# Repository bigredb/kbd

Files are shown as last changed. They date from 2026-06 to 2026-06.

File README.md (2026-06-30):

# Zigbee Touch Keypad

I wanted a door keypad that actually looked good on the wall — slim, wireless, no visible screws, no cloud dependency. Something I could mount next to the front door, punch in a code, and have Home Assistant react instantly. Off-the-shelf Zigbee keypads exist, but they're usually expensive, mains-powered, or locked to one ecosystem. So I built my own.

The result is a battery-powered touch keypad about the size of a pez dispenser. It runs for roughly **six months** on a single charge, talks **Zigbee** to whatever coordinator you already run, and wakes from deep sleep the moment you touch a key. This repo has everything you need to build one yourself: Gerber files, a 3D-printable case, and working firmware.

The firmware ships as a **Zigbee** end-device example. The same **ESP32-C6** board is equally happy running **Matter** or **Thread** — the touch handling and power logic stay the same; only the radio stack changes.

<p align="center">
  <a href="https://www.youtube.com/watch?v=2Mcdj70jt44">
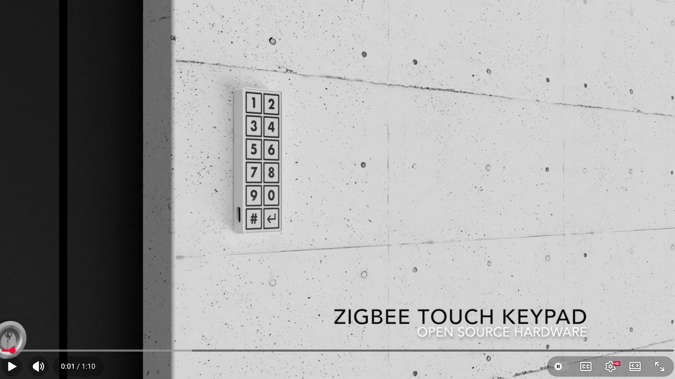
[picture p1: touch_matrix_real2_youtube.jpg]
Watch the keypad demo on YouTube
    
  </a>
</p>

## What it looks like on the wall

The design goal was something that disappears into a modern entryway. A white slab on textured walls, twelve touch buttons, no mechanics to wear out.

<p align="center">
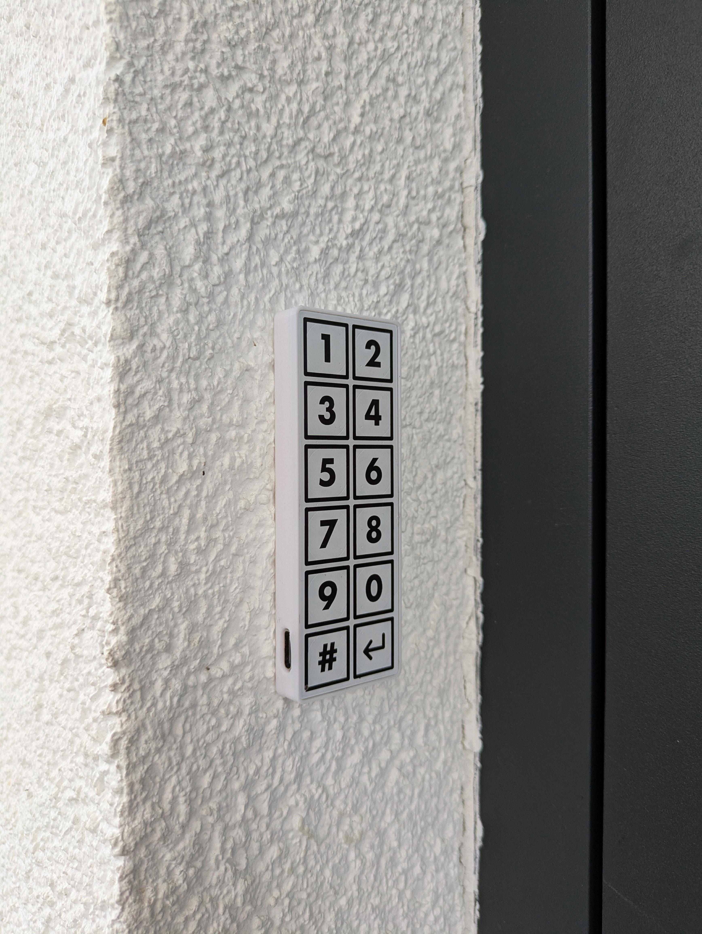
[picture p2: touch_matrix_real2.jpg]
Finished keypad mounted on a wall beside a door
  
</p>

Early renders explored proportions and mounting position before the first PCB arrived. Getting the aspect ratio right mattered — too tall and it looks just weird, too wide and it reads as a light switch.

<p align="center">
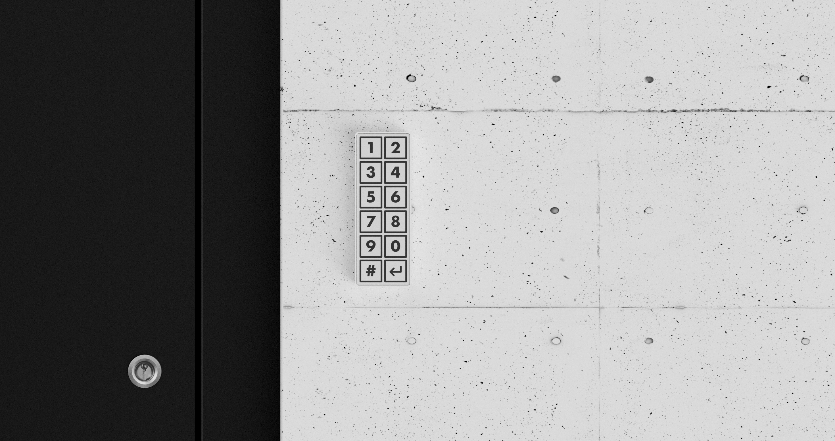
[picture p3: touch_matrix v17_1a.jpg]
Early prototype mounted on a concrete wall
  
 </p>

The front panel is a 2×6 grid: digits **1–9**, **0**, a **clear** key, and **enter**. Labels are printed directly on the PCB solder mask — no separate overlay, no glue, nothing to peel off after two winters.

---

## Tear it down

Pop the case apart and the internals are deliberately simple. A custom backplane PCB, a 1300 mAh LiPo filling most of the volume, and an ESP32-C6 dev board at the bottom with a USB-C port for charging and flashing.

<p align="center">
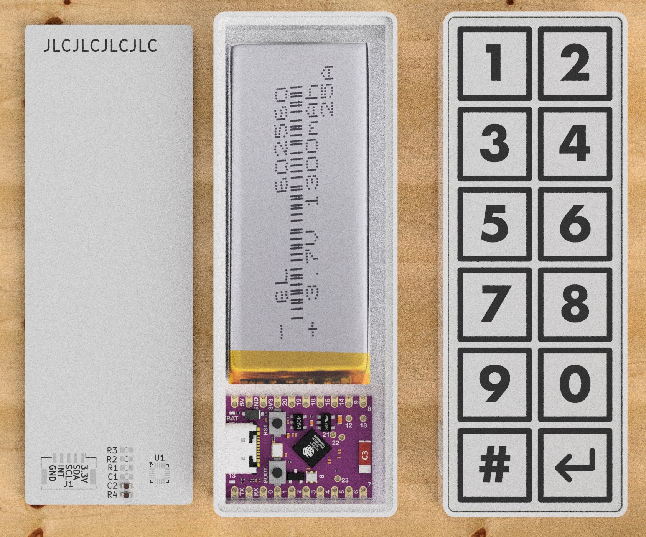
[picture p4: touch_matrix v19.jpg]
Exploded view showing PCB back, battery and ESP32 assembly, and keypad face
  
</p>

The whole assembly is rather light hence can be mounted to the wall with a few bites of white tack. For scale:

<p align="center">
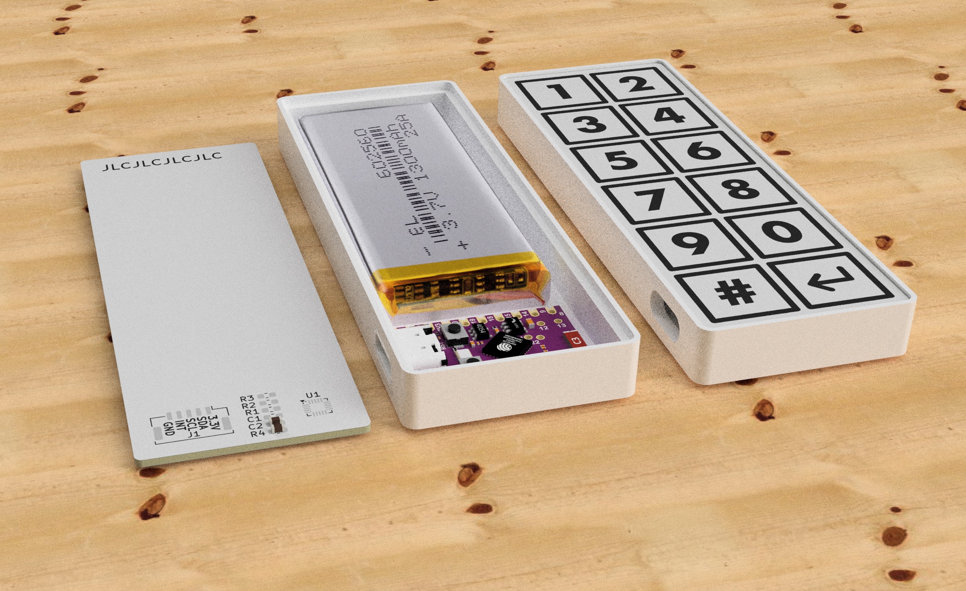
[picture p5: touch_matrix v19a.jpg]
Exploded assembly on a wooden workbench
  
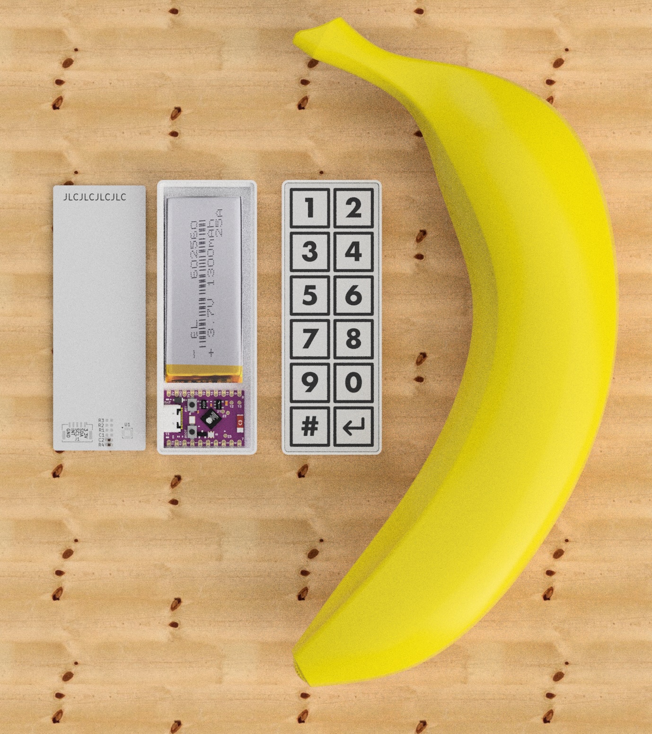
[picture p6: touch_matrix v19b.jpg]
All parts laid out next to a banana for size comparison
  
</p>

Three layers, top to bottom:

1. **Keypad face** — the touch matrix PCB you see and press
2. **Electronics bay** — battery, ESP32-C6, MPR121 touch controller
3. **Back cover** — 3D-printed shell (`case_mid_final.stl`) that clips on without screws

The onboard LED sits inside the white case that is somewhat translucent. When the device wakes from deep sleep it glows briefly; each key press flashes it again so you always know your touch registered.

---

## Order the PCB

You don't need to lay out a board from scratch. The Gerber files are in this repo and ready to upload to any fab. I've been using [JLCPCB](https://jlcpcb.com) — pick a colour scheme, drop in the matching zip, and order. No CAM fixes, no layer renaming, no back-and-forth with support.

| File | Colour scheme |
|---|---|
| `touch_matrix_Y24.zip` | **Black on white** — black key labels on a white PCB (latest revision) |
| `touch_matrix_Y23.zip` | **White on black** — white key labels on a black PCB |

Same layout, same touch pads — only the silkscreen colours differ. Choose whichever fits your wall and enclosure.

The back of the PCB carries the JLC order markings and a five-pin header for the MPR121:

| Pin | Function |
|-----|---|
| GND | Ground |
| INT | Interrupt (wake from sleep) |
| SCL | I²C clock |
| SDA | I²C data |
| 3.3 V | Power |

---

## Wire it up

The firmware expects this pin mapping on the ESP32-C6 DevKitC-1:

| Signal | GPIO | Notes |
|---|---|---|
| I²C SDA | 18 | MPR121 data |
| I²C SCL | 4 | MPR121 clock |
| IRQ | 6 | MPR121 interrupt — also the deep-sleep wake source |
| Battery ADC | 2 | Voltage divider input |
| BOOT button | 9 | Hold 3 s for Zigbee factory reset |

The wiring is very straigtforward - simply connect all the pins as described, connect the battery to ESP32-C6 bat pins, route 3.3V and ground to the PCB and done. If you would like the battery SOC reported, you will need to add an additional voltage device to the battery pins. 

The twelve MPR121 channels map to the front-panel keys like this:

| Channel | Key |
|---|-----|
| 0–8 | 1 – 9 |
| 9 | 0 |
| 10 | Clear |
| 11 | Enter |

For now the software allows coes up to eight digits.

---

## Flash the firmware

The project builds with [PlatformIO](https://platformio.org/). Clone the repo, connect the ESP32-C6 over USB-C, and:

```bash
pio run --target upload
```

To watch the serial log while pairing:

```bash
pio device monitor
```

The build targets **Zigbee end-device mode** (`ZIGBEE_MODE_ED`) with a custom partition table (`partitions_zigbee.csv`) that reserves flash for Zigbee network storage. Dependencies are pulled automatically — the main one is the Adafruit MPR121 library.

---

## Join your Zigbee network

On first boot the keypad scans for a coordinator. Dots print on the serial console at 115200 baud until it joins. In Home Assistant that means adding it through ZHA or Zigbee2MQTT — the device shows up as manufacturer **DrDoms**, model **KeyPad2**.

Two Zigbee endpoints are exposed:

| Endpoint | Cluster | What it reports |
|---|---|---|
| 1 | Analog Input + Battery | Entered passcode, battery voltage |
| 2 | Analog Input | Battery state of charge (%) |

The passcode flow works like this:

1. Touch digits on the pad — the LED confirms each press.
2. Press **Enter**. The code is reported on endpoint 1 as an analog value.
3. Battery level is reported at the same time.
4. Two seconds later the reported value resets to **0**, ready for the next entry.

**Leading 1:** The firmware always prepends a **1** to every code before sending it. The input buffer starts as `"1"` and resets to `"1"` after clear or enter. This is because ensure that leading zeros in your entered code are not stripped as the value is purely numeric, not a string. 

Press **Clear** at any time to wipe the buffer and start over.

### Home Assistant with ZHA

Once the keypad is flashed, getting it into [Home Assistant](https://www.home-assistant.io/) through [ZHA](https://www.home-assistant.io/integrations/zha/) takes about two minutes.

1. In Home Assistant go to **Settings → Devices & Services → Zigbee Home Automation** and open your coordinator.
2. Click **Add device** and confirm — this opens the network for joining.
3. Wake the keypad by touching any key. Within a few seconds it should appear as **DrDoms KeyPad2**.
4. Finish the interview if ZHA asks — no special configuration is needed.

After pairing, open the device page and note the entity names ZHA created. The important one is the **Passcode** analog-input sensor — in my setup it shows up as `sensor.drdoms_keypad2_passcode`. You will also see battery voltage and percentage sensors from the second endpoint. Entity IDs can differ slightly depending on your ZHA version and how many Espressif devices you already have, so always copy the names from your own device page rather than assuming mine.

When you enter a code and press **Enter**, that sensor updates to the numeric value of your input — including the leading **1** described above — holds it for two seconds, then drops back to **0**. That brief window is what your automations listen for.

The file `keypad_automation.yaml` is a worked example that maps passcodes to actions — opening a door, raising a cover, closing a cover. Import it as a starting point and adapt it to your home:

1. Go to **Settings → Automations & Scenes → Create Automation → Edit in YAML** (top-right menu).
2. Paste the contents of `keypad_automation.yaml`, or save the file to your Home Assistant `packages/` folder if you use [packages](https://www.home-assistant.io/docs/configuration/packages/).
3. Replace every `entity_id` with the ones from your installation — the passcode sensor, the door button, the cover, and so on.
4. Change the template values to match the codes you actually want. Each `if` block compares the passcode sensor against a number; when they match, the action runs. Remember to account for the leading **1** — the sample value `12345` means you typed **2-3-4-5** on the pad, not **1-2-3-4-5**. A code you enter as **0-1** will appear as **101** in Home Assistant.

```yaml
# Example: open a cover when passcode 12345 is entered
- if:
    - condition: template
      value_template: "{{ states('sensor.drdoms_keypad2_passcode') | int(0) == 12345 }}"
  then:
    - action: cover.open_cover
      target:
        entity_id: cover.basement_control_cover
```

The sample automation listens on two sensor entities because entity naming changed between ZHA versions — `sensor.espressif_zigbeeanalogdevice_power` is the older name, `sensor.drdoms_keypad2_passcode` is the current one. Keep whichever matches your device and delete the other trigger block.

To find the exact integer your keypad sends for a given code, enter the code, press **Enter**, and watch the sensor in **Developer Tools → States**. Use that number in your template condition.

### Matter and Thread

This repo demonstrates Zigbee because it's the fastest path to a working smart-home integration. But the ESP32-C6 has a native 802.15.4 radio, so porting to **Thread** and **Matter** is straightforward — the touch scanning, debouncing, battery ADC, and deep-sleep wake logic in `main.cpp` don't care which protocol sends the numbers upstream. Espressif's [ESP-Matter](https://github.com/espressif/esp-matter) SDK is the place to start if you want to go that route.

---

## Power: six months on a charge

Battery life was the hardest constraint. A keypad that's dead every two weeks is worse than no keypad at all.

The trick is aggressive deep sleep. After ten seconds without a touch, the firmware shuts everything down and puts the MPR121 into its slowest scan rate. The ESP32-C6 draws almost nothing. The next finger on the pad pulls the MPR121 interrupt line low, the MCU wakes, re-initialises I²C, and is ready to scan within milliseconds.

With a 1300 mAh cell and typical use — a few code entries per day — that works out to roughly **half a year** between USB-C charges. Battery voltage and percentage are reported over Zigbee so you can set a low-battery alert in Home Assistant before it goes flat.

---

## Day-to-day use

1. Walk up and touch a key. The LED glows through the case as the device wakes.
2. Enter your code. Each digit flashes the LED.
3. Press **Enter** to send it to your automation.
4. Walk away. Ten seconds later it sleeps again.

If you need to re-pair — new coordinator, corrupted network, that sort of thing — hold the **BOOT** button for more than three seconds. The device factory-resets its Zigbee stack and reboots.

---

## What's in this repo

```
keypad/
├── main.cpp                  # Touch handling, Zigbee reporting, power management
├── platformio.ini            # Board target, libraries, build flags
├── partitions_zigbee.csv     # Flash layout with Zigbee storage partitions
├── case_mid_final.stl        # 3D-printable enclosure mid-section
├── touch_matrix_Y24.zip      # PCB Gerbers — black on white
├── touch_matrix_Y23.zip      # PCB Gerbers — white on black
├── keypad_automation.yaml    # Home Assistant example — passcode → actions
└── touch_matrix_*.jpg        # Photos from the build
```

---

## License

| Part | License | File |
|---|---|---|
| Firmware (`main.cpp`, build config) | [MIT License](LICENSE) | `LICENSE` |
| Hardware (PCB Gerbers, STL, design files) | [CERN Open Hardware Licence v2 — Strongly Reciprocal](LICENSE.hardware) | `LICENSE.hardware` |

It really works well - has been my method of entry for the past year. If you make a variant — Matter port, different key layout, waterproof enclosure — I'd love to see it.

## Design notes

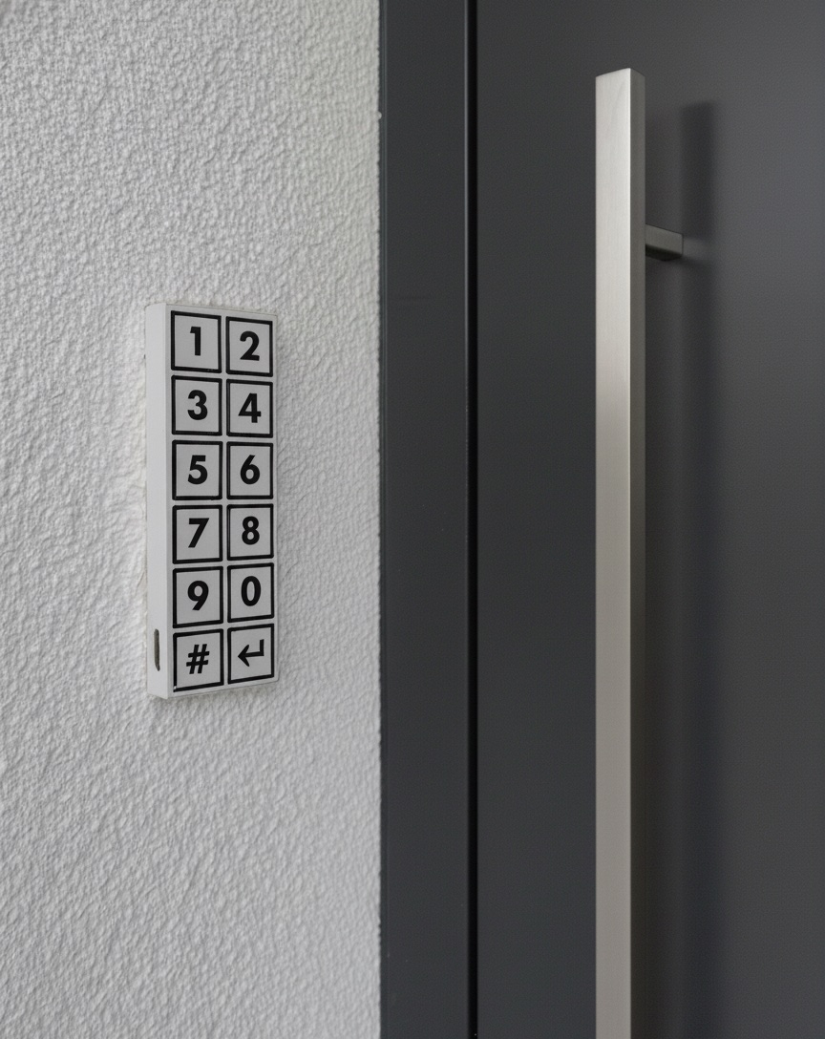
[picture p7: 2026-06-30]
touch_matrix_real.jpg

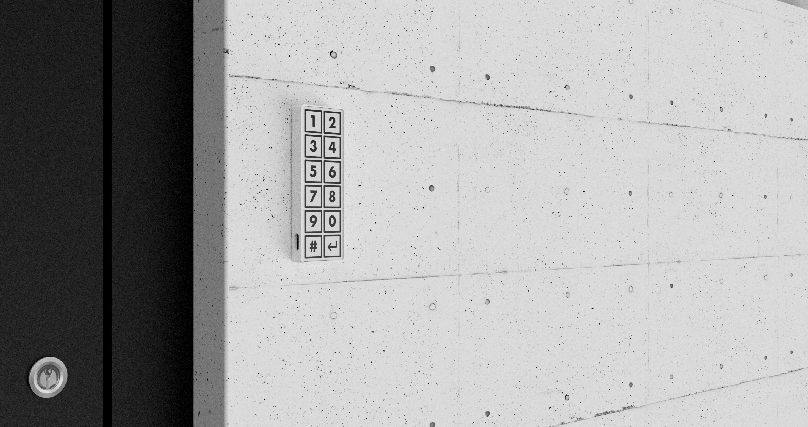
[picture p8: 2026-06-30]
touch_matrix v17_1b.jpg

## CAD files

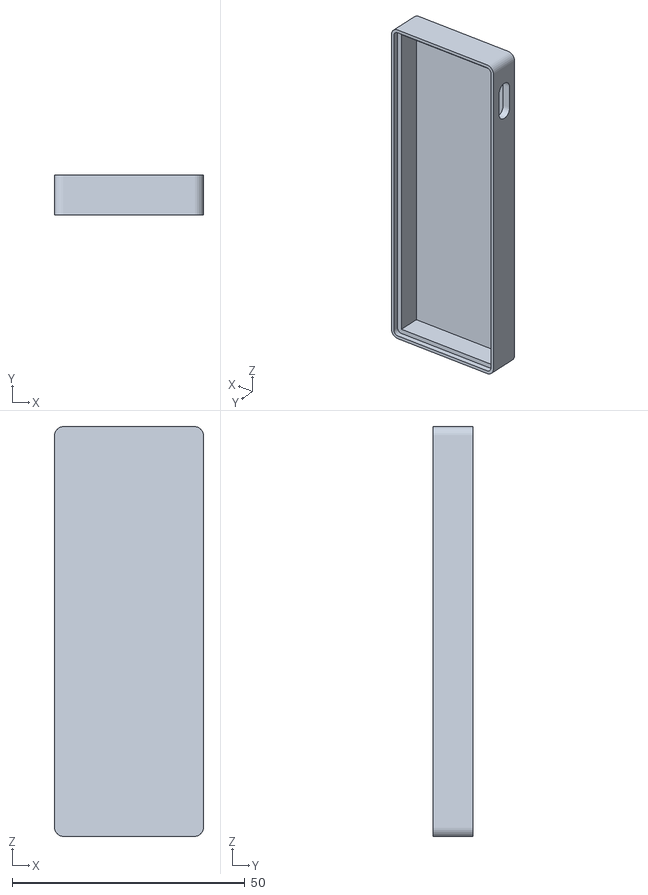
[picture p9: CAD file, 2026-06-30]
case_mid_final.stl
32.0 x 8.50 x 88.0

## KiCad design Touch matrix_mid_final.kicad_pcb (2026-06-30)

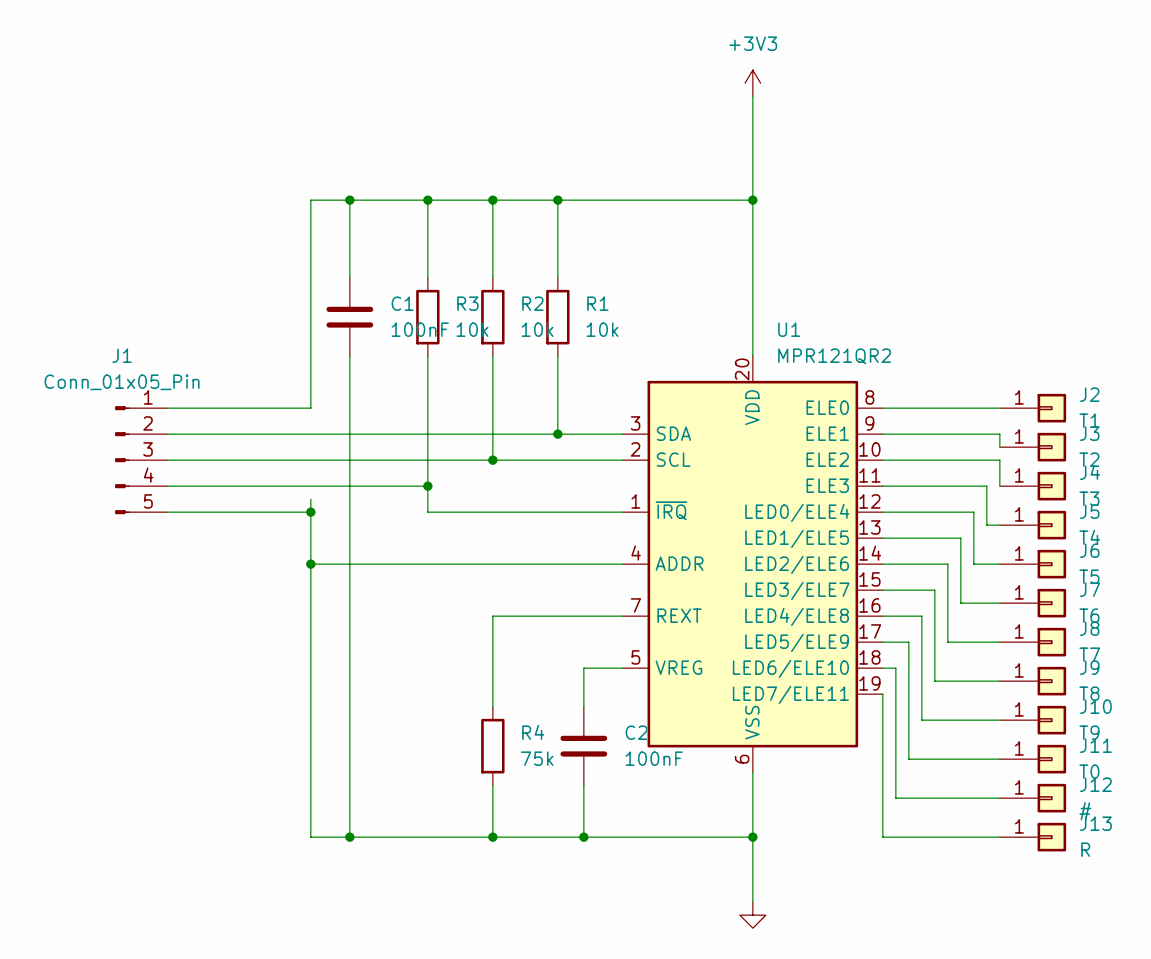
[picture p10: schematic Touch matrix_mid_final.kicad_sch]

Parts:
C1, C2: 100nF; C_0603_1608Metric
J1: Conn_01x05_Pin; Molex_CLIK-Mate_502382-0570_1x05-1MP_P1.25mm_Vertical
J2: T1; touch_pad_mod
J3: T2; touch_pad_mod
J4: T3; touch_pad_mod
J5: T4; touch_pad_mod
J6: T5; touch_pad_mod
J7: T6; touch_pad_mod
J8: T7; touch_pad_mod
J9: T8; touch_pad_mod
J10: T9; touch_pad_mod
J11: T0; touch_pad_mod
J12: #; touch_pad_mod
J13: R; touch_pad_mod
R1, R2, R3: 10k; C_0603_1608Metric
R4: 75k; C_0603_1608Metric
U1: MPR121QR2; UQFN-20_3x3mm_P0.4mm

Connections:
+3V3: C1.1, J1.1, R1.1, R2.1, R3.1, U1.20 (VDD)
GND: C1.2, C2.2, J1.5, R4.2, U1.4 (ADDR), U1.6 (VSS)
unnamed: J1.2, R1.2, U1.3 (SDA)
unnamed: J1.3, R2.2, U1.2 (SCL)
unnamed: J1.4, R3.2, U1.1 (~IRQ)
unnamed: J2.1, U1.8 (ELE0)
unnamed: J3.1, U1.9 (ELE1)
unnamed: J4.1, U1.10 (ELE2)
unnamed: J5.1, U1.11 (ELE3)
unnamed: J6.1, U1.12 (LED0/ELE4)
unnamed: J7.1, U1.13 (LED1/ELE5)
unnamed: J8.1, U1.14 (LED2/ELE6)
unnamed: J9.1, U1.15 (LED3/ELE7)
unnamed: J10.1, U1.16 (LED4/ELE8)
unnamed: J11.1, U1.17 (LED5/ELE9)
unnamed: J12.1, U1.18 (LED6/ELE10)
unnamed: J13.1, U1.19 (LED7/ELE11)
unnamed: R4.1, U1.7 (REXT)
unnamed: C2.1, U1.5 (VREG)

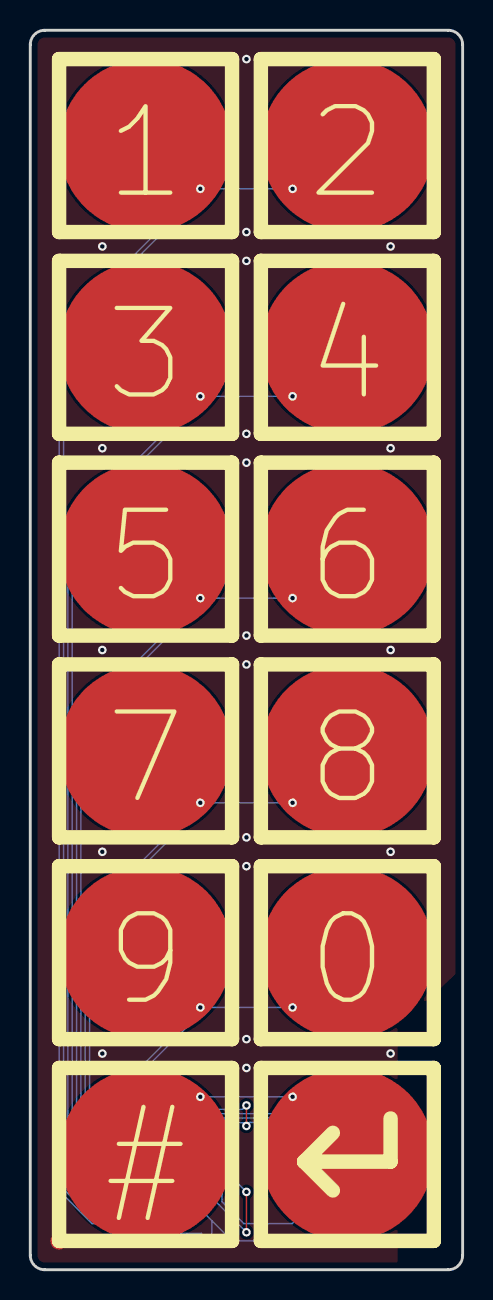
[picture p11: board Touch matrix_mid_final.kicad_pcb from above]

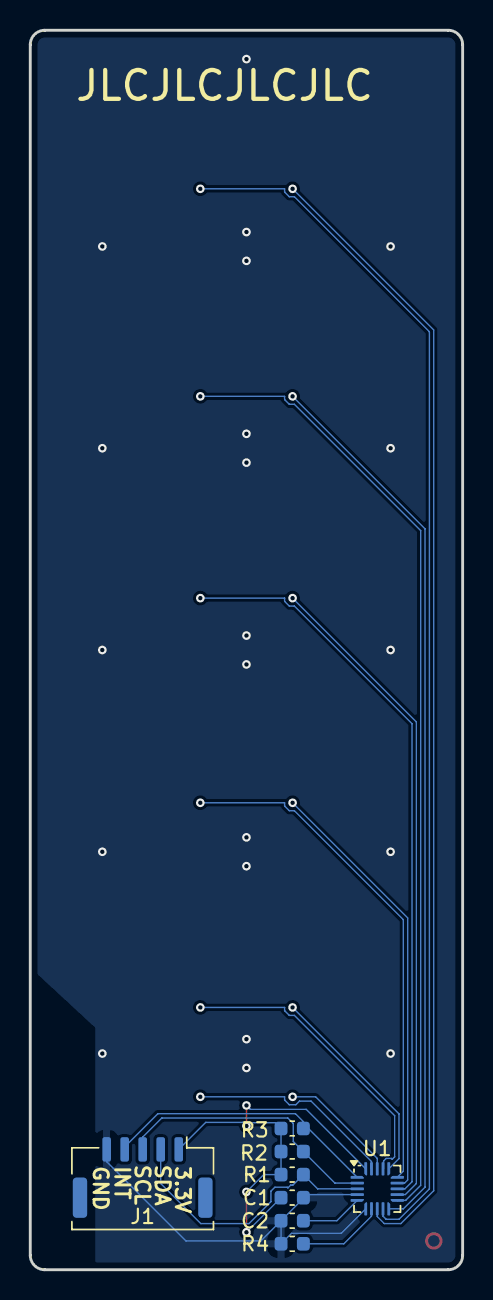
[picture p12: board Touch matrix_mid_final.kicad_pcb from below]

Board: 2 copper layers, 30.0 x 86.0 mm, 20 parts (8 on the bottom side), 19 nets.

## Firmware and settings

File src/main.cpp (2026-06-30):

/**
 * ESP32-C6 Zigbee Keypad with MPR121 Touch Sensor
 * 
 * Based on Espressif Arduino-ESP32 Zigbee examples
 * Uses proper initialization sequence: Configure endpoints -> Add to Zigbee -> Begin
 */

 #include "esp32-hal-gpio.h"
#ifndef ZIGBEE_MODE_ED
 #error "Zigbee end device mode is not selected in Tools->Zigbee mode"
 #endif



#include "Zigbee.h"
#include <Arduino.h>
#include <Wire.h>
#include <Adafruit_MPR121.h>
#include <esp_sleep.h>
#include <nvs_flash.h>
#include <nvs.h>

 

 uint8_t button = BOOT_PIN;

 // Pin Configuration
 const int SDA_PIN = 18;
 const int SCL_PIN = 4;
 const int IRQ_PIN = 6;
 const int BATTERY_PIN = 2;
 const int BUZZER_PIN = 15;
 const int BOOT_BUTTON_PIN = 9;
 
 // MPR121 object
 Adafruit_MPR121 cap = Adafruit_MPR121();
 
 // Last touch state
 uint16_t lastTouchState = 0;
 
 // Keypad input string
 String inputString = "1";
 const int MAX_INPUT_LENGTH = 8;
 
 // Deep sleep configuration
 const unsigned long SLEEP_TIMEOUT_MS = 10000; // 20 seconds
 unsigned long lastActivityTime = 0;
 
 // Debounce configuration
 const unsigned long DEBOUNCE_DELAY_MS = 100;
 unsigned long lastKeyPressTime = 0;
 
// Buzzer control
const unsigned long BEEP_DURATION_MS = 20;
unsigned long beepEndTime = 0;
bool beepActive = false;

// Zero code timeout (send zero 2 seconds after entering a code)
const unsigned long ZERO_CODE_TIMEOUT_MS = 2000;
unsigned long enterPressTime = 0;
bool waitingForZeroSend = false;
 
 // Zigbee endpoints - MUST be created as global variables
 #define BATTERY_ENDPOINT 1
 #define INPUT_ENDPOINT 2
 
 ZigbeeAnalog zbAnalogDevice = ZigbeeAnalog(BATTERY_ENDPOINT);
 ZigbeeAnalog zbAnalogSOC = ZigbeeAnalog(INPUT_ENDPOINT);
 
 // Map channel to keypad character
 char getKeypadChar(int channel) {
   if (channel >= 0 && channel <= 8) {
     return '1' + channel; // '1' to '9'
   } else if (channel == 9) {
     return '0';
   } else if (channel == 10) {
     return 'C'; // Clear
   } else if (channel == 11) {
     return 'E'; // Enter
   }
   return '\0';
 }

  int get_battery_SOC()
  {
     // Sample battery voltage 10 times with 10ms delay and take average
     long batteryRawSum = 0;
     for (int i = 0; i < 10; i++) {
       batteryRawSum += analogRead(BATTERY_PIN);
       delay(10);
     }
     int batteryRaw = batteryRawSum / 10;
     
     float batteryVoltage = (batteryRaw / 4095.0) * 3.3 * 2.0 *1.28;
    float batterySOC=(batteryVoltage-3.2);
    if (batterySOC<0.0)
      batterySOC=0.0;
    if (batterySOC>1.0)
      batterySOC=1.0;
    batterySOC=batterySOC*100.0;

    Serial.print("Battery Voltage: ");
    Serial.print(batteryVoltage, 2);
    Serial.print("Battery %: ");
    Serial.println(batterySOC);


    zbAnalogDevice.setBatteryPercentage(int(batterySOC));
    zbAnalogDevice.setBatteryVoltage(int(batteryVoltage*10.0));

    zbAnalogDevice.reportBatteryPercentage();


    return(batterySOC);
 }
 
 void handleKeypadInput(int channel) {
   char key = getKeypadChar(channel);
   
   if (key == '\0') return;
   
  // Trigger beep
  beepActive = true;
  beepEndTime = millis() + BEEP_DURATION_MS;
  digitalWrite(BUZZER_PIN, HIGH);
   
   if (key == 'C') {
     inputString = "1";
     Serial.println("Input: []");
  } else if (key == 'E') {
    Serial.print("ENTER - Input: [");
    Serial.print(inputString);
    Serial.println("]");
    
    long inputValue = inputString.length() > 0 ? inputString.toInt() : 0;
    
    
    
    // Report to Zigbee
    zbAnalogDevice.setAnalogInput((float)inputValue);
    zbAnalogDevice.reportAnalogInput();
    zbAnalogSOC.setAnalogInput(get_battery_SOC());
    zbAnalogSOC.reportAnalogInput();
    
    

    
    // Start timer to send zero code after 2 seconds
    enterPressTime = millis();
    waitingForZeroSend = true;
    
    inputString = "1";
   } else {
     if (inputString.length() < MAX_INPUT_LENGTH) {
       inputString += key;
       Serial.print("Input: [");
       Serial.print(inputString);
       Serial.println("]");
     } else {
       Serial.println("Max 8 digits reached!");
     }
   }
 }
 
void enterDeepSleep() {
  Serial.println("Setting MPR121 to slowest update rate for low power...");
  cap.writeRegister(MPR121_CONFIG2, 0x3F);
   
   Serial.println("Entering deep sleep...");
   Serial.flush();
   
   digitalWrite(BUZZER_PIN, LOW);
   //gpio_pullup_en(GPIO_NUM_6);

  // Initialize pins
  pinMode(IRQ_PIN, INPUT);
  pinMode(BUZZER_PIN, INPUT);
  pinMode(BOOT_BUTTON_PIN, INPUT);
  pinMode(SDA_PIN, INPUT);
  pinMode(SCL_PIN, INPUT);
  pinMode(IRQ_PIN, INPUT);

   
   esp_deep_sleep_enable_gpio_wakeup(1ULL << IRQ_PIN, ESP_GPIO_WAKEUP_GPIO_LOW);
   esp_deep_sleep_start();
 }
 
void setup() {
  // WRITE_PERI_REG(CONFIG_ESP_BROWNOUT_DET, 0);  // REMOVED - causes crash!

  Serial.begin(115200);
   //while (!Serial && millis() < 3000);
   Serial.println("ESP32-C6 Zigbee Keypad");
   //delay(1000);
   
   // Initialize pins
   pinMode(IRQ_PIN, INPUT_PULLUP);
   pinMode(BATTERY_PIN, INPUT);
   pinMode(BUZZER_PIN, OUTPUT);
   digitalWrite(BUZZER_PIN, LOW);
   pinMode(BOOT_BUTTON_PIN, INPUT_PULLUP);
   digitalWrite(BUZZER_PIN, HIGH);
   

  // Optional: set Zigbee device name and model
   zbAnalogDevice.setManufacturerAndModel("DrDoms", "KeyPad2");
   zbAnalogDevice.setPowerSource(ZB_POWER_SOURCE_BATTERY, 100, 42);

 
   // Set up analog input
   zbAnalogDevice.addAnalogInput();
   zbAnalogDevice.setAnalogInputApplication(ESP_ZB_ZCL_AI_COUNT_UNITLESS_OTHER);
   zbAnalogDevice.setAnalogInputDescription("Passcode");
   zbAnalogDevice.setAnalogInputResolution(1);
   // Set up analog input
  zbAnalogSOC.addAnalogInput();
  zbAnalogSOC.setAnalogInputApplication(ESP_ZB_ZCL_AI_PERCENTAGE_OTHER);
  zbAnalogSOC.setAnalogInputDescription("Battery SOC");
  zbAnalogSOC.setAnalogInputResolution(1);


 // Add endpoints to Zigbee Core
 Zigbee.addEndpoint(&zbAnalogDevice);
 Zigbee.addEndpoint(&zbAnalogSOC);

  // Initialize NVS for Zigbee data persistence
  esp_err_t ret = nvs_flash_init();
  if (ret == ESP_ERR_NVS_NO_FREE_PAGES || ret == ESP_ERR_NVS_NEW_VERSION_FOUND) {
    ESP_ERROR_CHECK(nvs_flash_erase());
    ret = nvs_flash_init();
  }
  ESP_ERROR_CHECK(ret);

  Serial.println("Starting Zigbee...");
  // When all EPs are registered, start Zigbee in End Device mode
  if (!Zigbee.begin(ZIGBEE_END_DEVICE)) {
     Serial.println("Zigbee failed to start!");
     Serial.println("Rebooting...");
     ESP.restart();
   } else {
     Serial.println("Zigbee started successfully!");
   }
   Serial.println("Connecting to network");
   while (!Zigbee.connected()) {
     Serial.print(".");
    
     delay(100);

     delay(100);
     

   }
   Serial.println("Connected");
   // Initialize I2C and MPR121
   Serial.println("Initializing MPR121...");
   Wire.begin(SDA_PIN, SCL_PIN);
   Wire.setClock(100000);
   delay(100);
   if (!cap.begin(0x5A)) {
     Serial.println("MPR121 not found!");
     ESP.restart();
     
   }
   
  cap.setAutoconfig(true);
  cap.setThresholds(8, 4);  // 12 touch, 6 release
  Serial.println("MPR121 initialized!");
   
   Serial.println("");
   Serial.println("=== Keypad Layout ===");
   Serial.println("Channels 0-8: Numbers 1-9");
   Serial.println("Channel 9: Number 0");
   Serial.println("Channel 10: Clear");
   Serial.println("Channel 11: Enter");
   Serial.println("Max 8 digits");
   Serial.println("Press BOOT for 3s to factory reset");
   Serial.println("====================");
   
   lastActivityTime = millis();

   digitalWrite(BUZZER_PIN, LOW);


}
 
 void loop() {
   uint16_t touchState = cap.touched();
   unsigned long currentTime = millis();
   
   // Check for new touches
   for (int i = 0; i < 12; i++) {
     uint16_t mask = 1 << i;
     bool currentlyTouched = touchState & mask;
     bool wasTouched = lastTouchState & mask;
     
     if (currentlyTouched && !wasTouched) {
       lastActivityTime = currentTime;
       
       if (currentTime - lastKeyPressTime > DEBOUNCE_DELAY_MS) {
         handleKeypadInput(i);
         lastKeyPressTime = currentTime;
       }
     }
   }
   
   lastTouchState = touchState;
   
  // Handle buzzer
  if (beepActive && millis() >= beepEndTime) {
    digitalWrite(BUZZER_PIN, LOW);
    beepActive = false;
  }
  
  // Check if we need to send zero code after timeout
  if (waitingForZeroSend && (millis() - enterPressTime >= ZERO_CODE_TIMEOUT_MS)) {
    Serial.println("Sending zero code...");
    zbAnalogDevice.setAnalogInput(0.0);
    zbAnalogDevice.reportAnalogInput();
    waitingForZeroSend = false;
  }
  
  // Checking button for factory reset and reporting
   if (digitalRead(button) == LOW) {  // Push button pressed
    // Key debounce handling
    delay(100);
    int startTime = millis();
    while (digitalRead(button) == LOW) {
      delay(50);
      if ((millis() - startTime) > 3000) {
        // If key pressed for more than 3secs, factory reset Zigbee and reboot
        Serial.println("Resetting Zigbee to factory and rebooting in 1s.");
        delay(1000);
        Zigbee.factoryReset();
      }
    }

  }
   // Check for sleep timeout
   if (millis() - lastActivityTime > SLEEP_TIMEOUT_MS) {
     enterDeepSleep();
   }
   
   delay(10);
 }
 
